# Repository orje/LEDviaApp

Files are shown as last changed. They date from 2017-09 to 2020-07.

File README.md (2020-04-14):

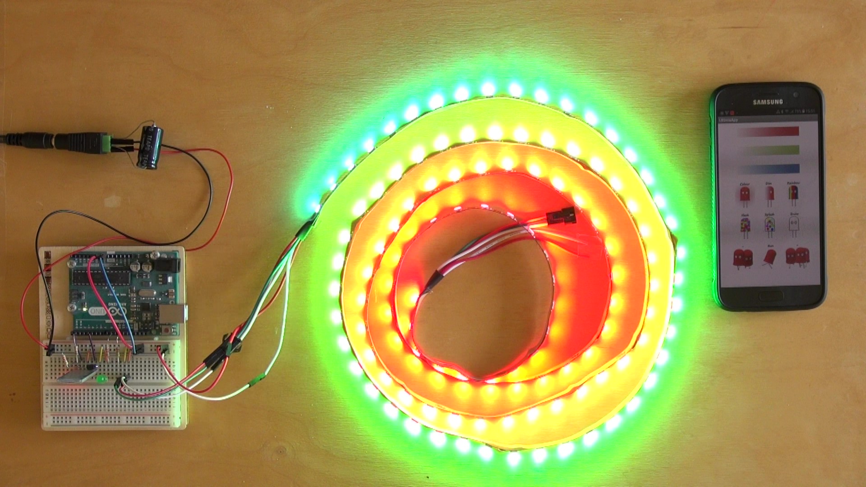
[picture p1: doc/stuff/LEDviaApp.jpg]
Demo video
  
[Demo video](https://youtu.be/p4o3Cnaa4Ys)

#### See the Wiki for further informations!
###### This file is at least needed. The ino file is generated throughout QM.
* LEDviaApp.qm = QM model file  
###### These files are originally [from](https://github.com/nickgammon/NeoPixels_SPI) here.
* NeoPixels_SPI.cpp = library from Nick Gammon  
* NeoPixels_SPI.h = library from Nick Gammon  
###### The app file:
* aia = exported source file for import in MIT App Inventor 2

###### The doc directory includes further files and informations.

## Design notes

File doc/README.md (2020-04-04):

* MIT App Inventor 2 apk file for installation  
* Fritzing file  
* pictures of breadboard and circuit

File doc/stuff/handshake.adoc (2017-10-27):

[uml,handshake.png]
----

hide footbox

title handshake between handy and Arduino

actor user #orange
control app #steelblue
entity handy #steelblue
entity Arduino #green
control sketch #green
entity LED #red

autonumber "<b>  #"

activate LED

Arduino -[#green]> sketch: Q_TIMEOUT

sketch <-[#green] Arduino: no request

sketch -[#green]> LED: control LED

user -[#orange]> app: input

== app starts handshake ==

app -[#steelblue]> Arduino: no communication ongoing \n send request 'R'

note right #lightgrey
byte goes straight
into receive buffer
end note

Arduino -[#green]> sketch: Q_TIMEOUT

sketch <-[#green] Arduino: see request 'R'

deactivate LED

== sketch continues handshake==

sketch -[#green]> handy: send transmit 'T'

handy -[#steelblue]> app: Clock Timer

app <-[#steelblue] handy: see permission 'T'

app -[#steelblue]> Arduino: send message '<XY>'

Arduino -[#green]> sketch: Q_TIMEOUT

sketch <-[#green] Arduino: get message '<XY>'

sketch -[#green]> handy: on stop sign '>' \n send acknowledge 'A'

== sketch ends handshake ==

sketch -[#green]> LED: control LED

activate LED

handy -[#steelblue]> app: Clock Timer

app <-[#steelblue] handy: see acknowledge 'A' \n end communication

== app ends handshake ==

Arduino -[#green]> sketch: Q_TIMEOUT

sketch <-[#green] Arduino: no request

sketch -[#green]> LED: control LED

----

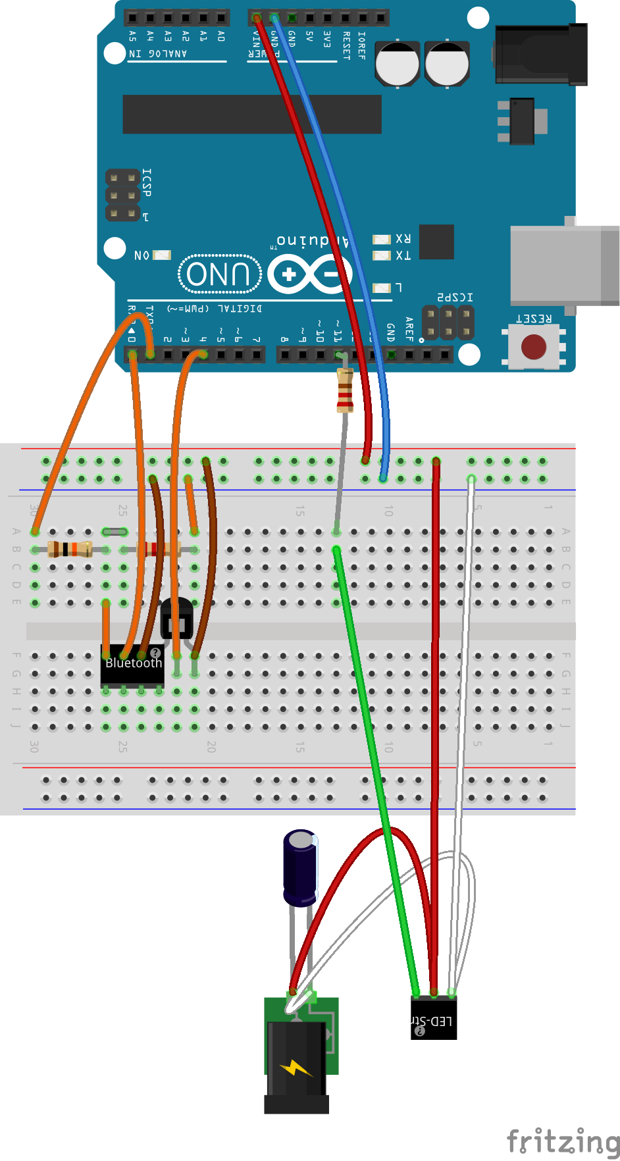
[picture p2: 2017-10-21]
doc/LEDviaApp_UNO_breadboard.png

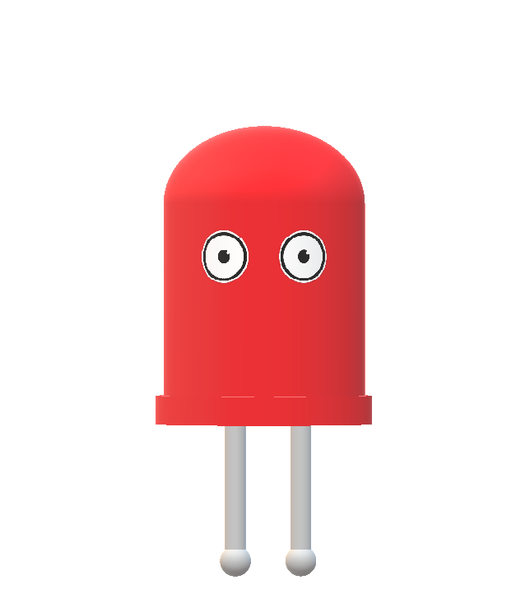
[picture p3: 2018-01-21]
doc/stuff/LedManV3/LedManWorkV3 - Kopie.png

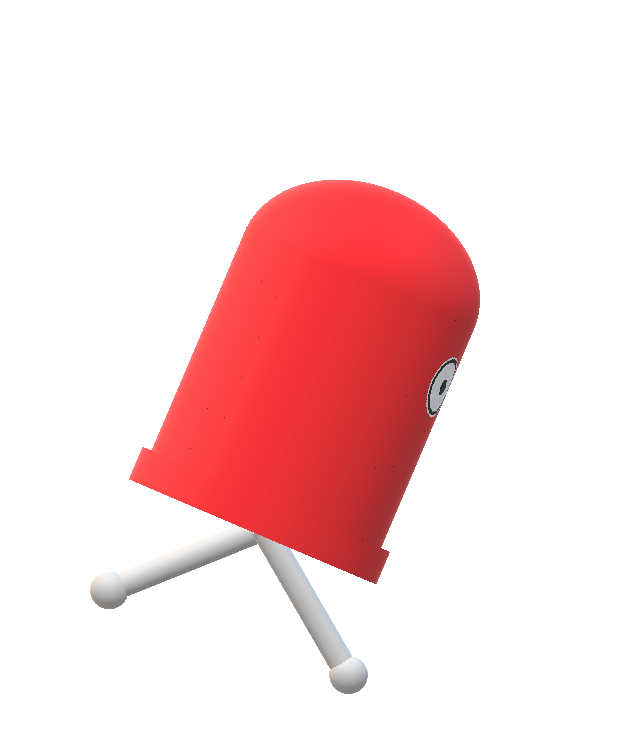
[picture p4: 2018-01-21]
doc/stuff/LedManV3/LedManRunV3.png

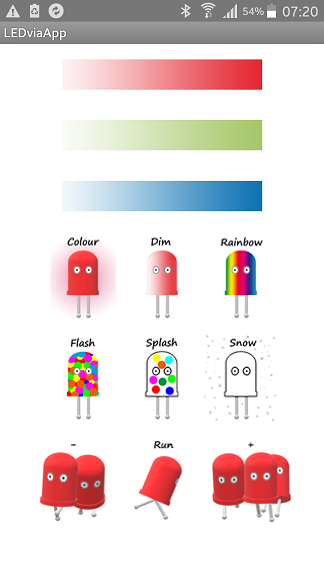
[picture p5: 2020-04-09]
doc/stuff/App.png

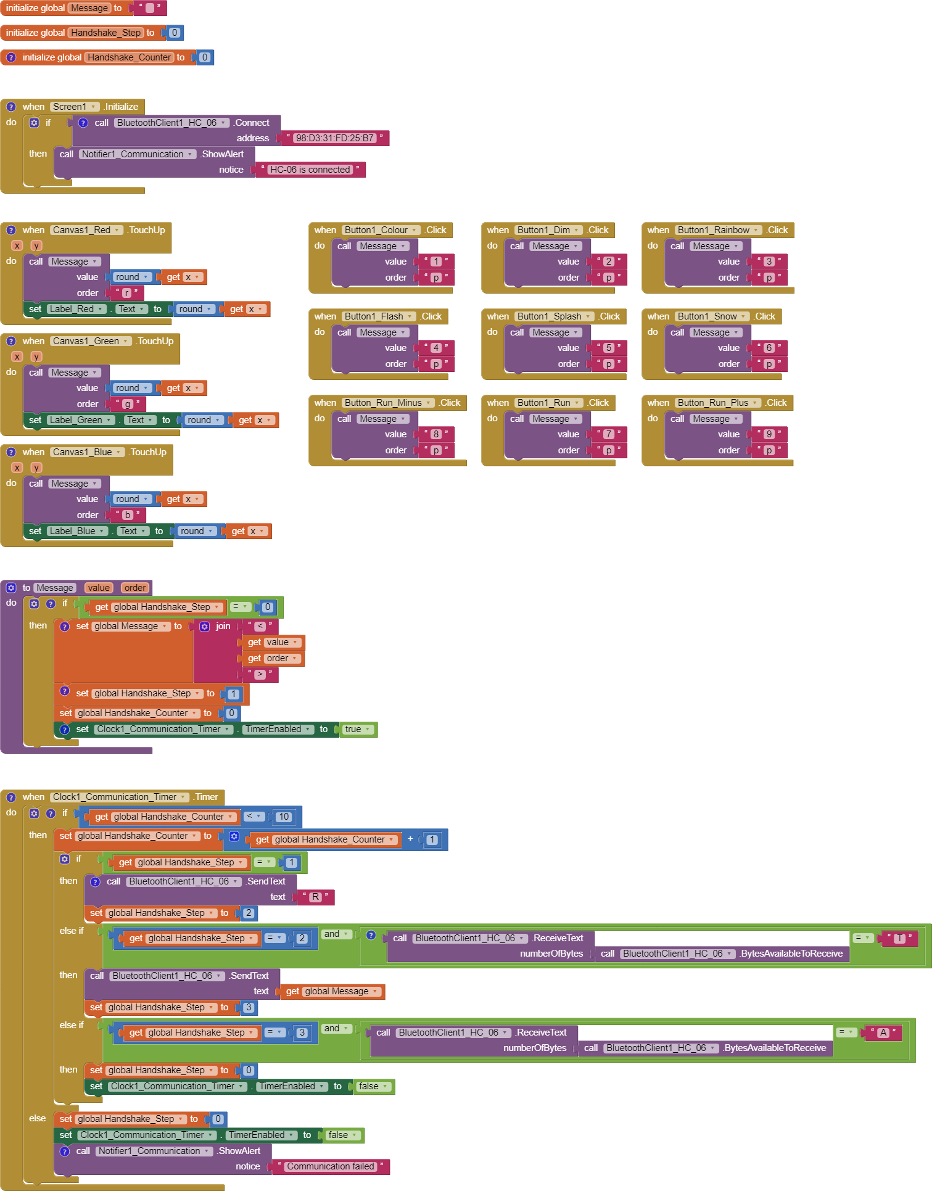
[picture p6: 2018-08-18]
doc/stuff/blocks.png

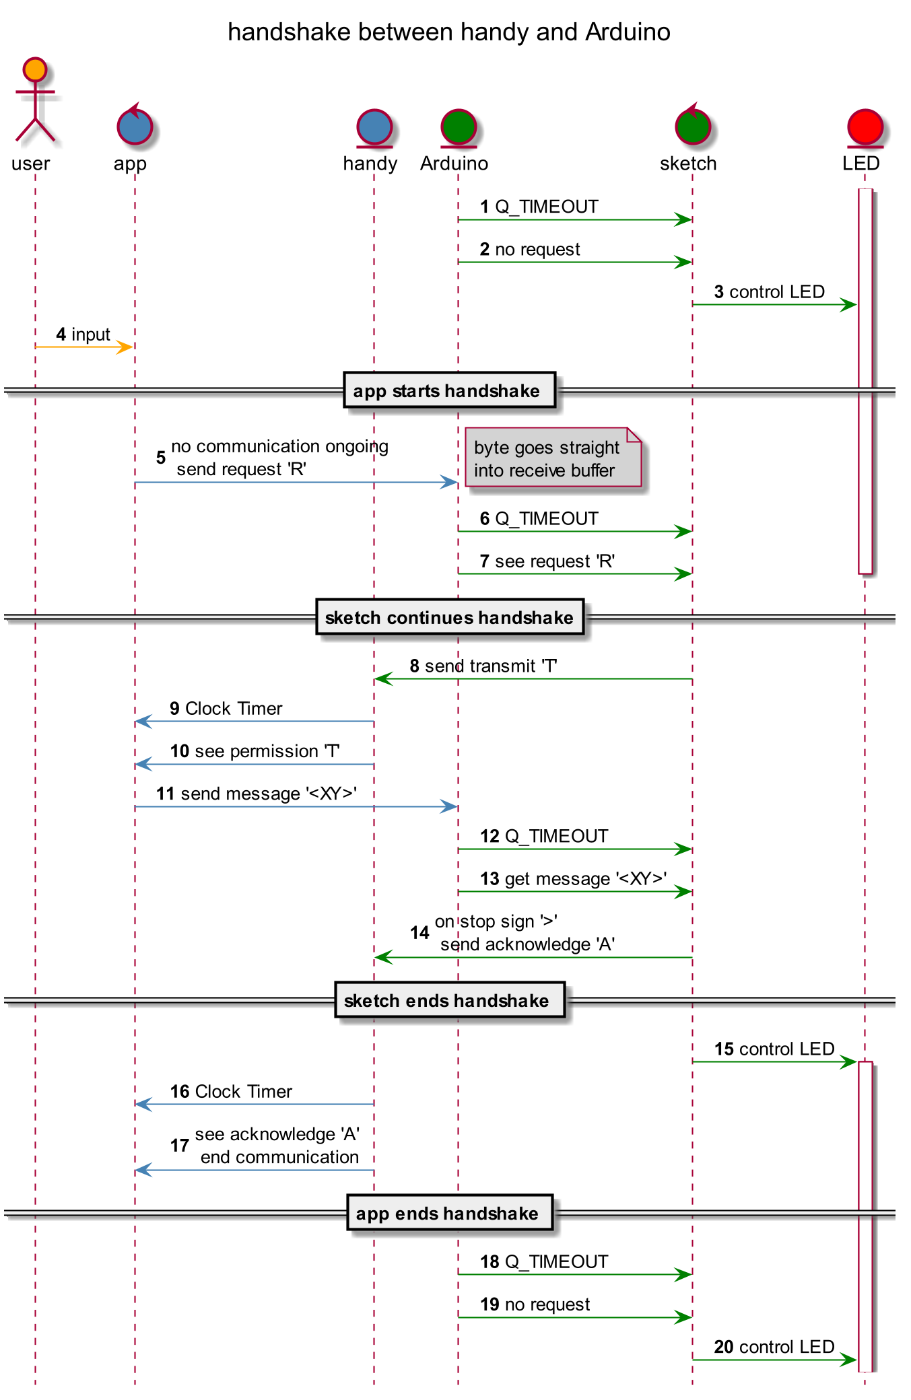
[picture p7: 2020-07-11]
doc/stuff/handshake.png

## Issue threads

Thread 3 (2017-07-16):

Initialisierungs-Datenübertragung bei Neuverbindung

orje, 2017-07-16:
Wenn bereits ein Anzeige-Programm im UNO läuft, muss ich bei einer Neuverbindung z.B. zu einem späteren Zeitpunkt erst einmal alle Werte auf 0 setzen und übertragen, sonst arbeiten app und sketch mit unterschiedlichen Werten und ich müsste erst einmal manuell alles auf 0 stellen.

orje, 2017-07-28:
Nicht wirklich nötig. Dann muss eben nach einer Neuverbindung die Werte so eingestellt werden, wie man sie haben möchte.

Closed 2017-07-28.

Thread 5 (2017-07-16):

Farbschieber auf 0 - 255 begrenzen

orje, 2017-07-16:
Z.Z. ist die Werteermittelung der Schieber irgendwie an die Bildschirmbreite gebunden. Daher ist es möglich, Werte > 255 einzustellen. Das stört zwar nicht, da sie schlichtweg nicht umgesetzt werden können, Ist aber ein Schönheitsfehler.

orje, 2017-07-28:
oder auch nicht

Closed 2017-07-28.

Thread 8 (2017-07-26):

Teststellung

orje, 2017-07-26:
Das Handy ballert die Werte einfach nur so raus. Das model reagiert auf den Interrupt der seriellen Schnittstelle und setzt die Befehle um, auch mitten in der Led Ansteuerung.

Die Interruptabschaltung in der libary und im model, während  LED-Ansteuerung, auskommentieren.

Was passiert aber dann, wenn zu jedem x-beliebigen Zeitpunkt eine Kommunikation reinkommt und die Led Ansteuerung unterbrochen und wieder neu/anders aufgenommen wird?

orje, 2017-07-28:
Habe alte Tests gefunden, welche darauf deuteten, dass es ohne Handshake nicht ordentlich funktioniert.

Closed 2017-07-28.

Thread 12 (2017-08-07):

Umgang mit Kommunikationshängern implementieren

orje, 2017-08-07:
Einen Zähler oder eine weitere Zykluszeitüberwachung mit der Kommunikation starten, um Hänger abzufangen.

orje, 2017-10-20:
bzw. asserts implentieren

orje, 2018-02-09:
Ebenso die Bluetooth Verbindung checken

orje, 2018-02-16:
done

Closed 2018-02-16.

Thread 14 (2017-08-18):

model restrukturieren

orje, 2017-08-18:
Um es noch übersichtlicher zu gestalten, könnte ich analog zum state communication im state branch von Q_TIMEOUT aus 4 choices machen, statt alles in der entry action abzufragen.
Dann würden sogar die events (DISPLAY, RUNNING_LIGHT, DIMMING) wegfallen.

orje, 2017-10-19:
Geht nicht so einfach, da zwei choices hintereinander geschaltet werden müssten (z.B. dimmen und dann up oder down)

Closed 2017-10-19.

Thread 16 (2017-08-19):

transition to history integrieren

orje, 2017-08-19:
Für die Rückkehr von state communication zu state branch nutzbar, um zum letzten aktiven program oder zu state display als default zu springen?

orje, 2017-09-03:
bringt nichts

Closed 2017-09-03.

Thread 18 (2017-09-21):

ursprüngliche Schieber testen

orje, 2017-09-21:
Theoretisch dürfte es nun keine Hänger mehr geben, da auf Seiten der App die Kommunikation und auf Seiten des UNO 1 LED-Zyklus erst abgeschlossen sein muss, bevor die nächste folgen kann.

orje, 2017-09-21:
gelabelt

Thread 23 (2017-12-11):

Anzahl der LED beim Lauflicht wählbar gestalten

orje, 2017-12-11:
Variante 1: Zahleneingabe
Variante 2: + oder - mit Zähler

orje, 2017-12-11:
Funktionsausbau

orje, 2018-01-02:
Zu 99% erledig.
Zwei Punkte sind mir unklar:
- Das Erreichen der Endpunkte (PIXELS und 0) ist unterschiedlich.
- Die Anzahl kann nicht bis auf Maximum (PIXELS und 0) geschraubt werden.

Closed 2018-01-02.

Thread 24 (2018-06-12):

aktuellen Farbwert in der App anzeigen

orje, 2018-06-12:
Die Programme Colour, Dim und Run arbeiten mit den Farben der Schieberegler. Die aktuell eingestellte Farbe sollte angezeigt werden.
Die Programme Rainbow, Flash, Splash und Snow generieren ihre eigenen Farbwerte.

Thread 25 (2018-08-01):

snow ist blöd

orje, 2018-08-01:
Der Schnee soll von oben nach unten fallen und ggf. sich über einen gewissen Zeitrum von unten nach oben stapeln.

orje, 2018-08-15:
oder schmilzen

orje, 2018-08-27:
Denkfehler, da ich nur mit dem 8 LED Pixel stick stehend teste. Der LED stripe wird horizontal angebracht und damit gibt's kein "von oben, nach unten".

Closed 2018-08-27.

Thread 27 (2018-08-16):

Handling des Kommunikationsfehlers vom Arduino bearbeiten

orje, 2018-08-16:
neuer Kommunikationsversuch der App setzt Fehler Led zurück

orje, 2018-08-27:
Ist ein Problem des neuen builds des MIT App Inventor 2.
Der legacy build funkitoniert.

Closed 2018-08-27.

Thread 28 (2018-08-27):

automatic reset of the Arduino, if communication hangs

orje, 2018-08-27:

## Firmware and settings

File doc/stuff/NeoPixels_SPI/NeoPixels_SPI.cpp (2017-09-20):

/*
 *
 * NeoPixel display library.
 *
 * Author: Nick Gammon
 * Date:   2nd March 2016
 *
 * With ideas from: http://wp.josh.com/2014/05/13/ws2812-neopixels-are-not-so-finicky-once-you-get-to-know-them/
 *
 * Designed for 16 MHz processor.
 *
 * Released for public use under the Creative Commons Attribution 3.0 Australia License
 *      http://creativecommons.org/licenses/by/3.0/au/
 *
 * In other words, if you use this code, please give me the credit for writing the library.
 *
 * Time taken to display: About 63 µs per pixel (21 µs per byte, about 2.6 µs per bit).
 * This is 63 ms to display 1000 pixels, roughly 16 refreshes per second (16 FPS)
 *   Of course, with less pixels the frame rate will go up.
 *
  HOW TO USE
    ledsetup ();         - Get ready to send.
                           Call once at the beginning of the program.
    sendPixel (r, g, b); - Send a single pixel to the string.
                           Call this once for each pixel in a frame.
                           Each colour is in the range 0 to 255.
    show ();             - Latch the recently sent pixels onto the LEDs .
                           Call once per frame.
    showColor (count, r, g, b); - Set the entire string of count Neopixels to this one colour.
                                  This automatically turns interrupts off, so you don't need to do it.
    Note that if you are sending individual pixels (with sendPixel) you should first call
    noInterrupts(), send all the pixels you need, and then call interrupts(). Otherwise a timer or
    other interrupt may pause the sending long enough for the string to reset.
    For example:
    noInterrupts ();          // prevent interrupts while we are sending colours
    for (byte i = 0; i < 10; i++)
      {
      sendPixel (100, 0, 0);    // red
      sendPixel (0, 100, 0);    // green
      sendPixel (0, 0, 100);    // blue
      } // end of for loop
    interrupts ();            // interrupts are OK now
    show ();                  // latch the colours
 */

#include <SPI.h>
#include <NeoPixels_SPI.h>

// Note: Connect NeoPixels to MOSI (pin D11 on a Uno, pin D51 on a Mega)

void sendByte (byte b)
  {
    // send one byte to the Neopixels - note that the "off" gap is partly handled by the loop overhead
    // gaps measured empirically to be 1.7 µs to 2 µs, so we don't need to add any more of our own
    for (byte bit = 0; bit < 8; bit++)
      {
	// byte b mit 0x80 = binär 10000000 ausmaskieren. Ergebnis ist 1, wenn erstes bit von b auch 1 ist.
      if (b & 0x80) // is high-order bit set?
        SPI.transfer (0b11111100);  // 1 bit - 750 ns on + 250 ns off (acceptable "on" range 550 ns to 850 ns)
      else
        SPI.transfer (0b11100000);  // 0 bit - 375 ns on + 625 ns off (acceptable "on" range 200 ns to 500 ns)
	// b = b << 1
      b <<= 1; // shift next bit into high-order position
    } // end of for each bit
} // end of sendByte

void ledsetup()
{
  SPI.begin ();
  SPI.setClockDivider (SPI_CLOCK_DIV2);
  SPI.setBitOrder (MSBFIRST);
  SPI.setDataMode (SPI_MODE1);   // MOSI normally low.
  show ();                       // in case MOSI went high, latch in whatever-we-sent
  sendPixel (0, 0, 0);           // now change back to black
  show ();                       // and latch that
}  // end of ledsetup

void sendPixel (const byte r, const byte g, const byte b)
  {
  sendByte (g);        // NeoPixel wants colors in green-then-red-then-blue order
  sendByte (r);
  sendByte (b);
  } // end of sendPixel

// Just wait long enough without sending any bits to cause the pixels to latch and display the last sent frame
void show()
  {
  delayMicroseconds (9);
  } // end of show

// Display a single color on the whole string
void showColor (const unsigned int count, const byte r , const byte g , const byte b)
  {
  noInterrupts ();
  for (unsigned int pixel = 0; pixel < count; pixel++)
    sendPixel (r, g, b);
  interrupts ();
  show ();  // latch the colours
  } // end of showColor

// for the rainbow animation  
// Input a value 0 to 255 to get a color value.
// The colours are a transition r - g - b - back to r.
void Wheel (byte WheelPos, byte & r, byte & g, byte & b) {
  if (WheelPos < 85) {
    r = WheelPos * 3;
    g = 255 - WheelPos * 3;
    b = 0;
    }
  else if (WheelPos < 170) {
    WheelPos -= 85;
    r = 255 - WheelPos * 3;
    g = 0;
    b = WheelPos * 3;
    }
  else {
    WheelPos -= 170;
    r = 0;
    g = WheelPos * 3;
    b = 255 - WheelPos * 3;
    }
} // end of Wheel

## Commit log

2017-07-14 Erster Upload
    Upload der Code-Dateien und der Dokumentationen
    [LEDviaApp.fzz]
2017-07-16 Redaktionelle Änderungen und Ergänzungen
2017-07-18 Stripe mit 120 LED
2017-07-21 Versuch ein Bild in die README-Datei zu bekommen
2017-07-22 Bild der state machine anzeigen
2017-07-23 kleinere Korrekturen
    [LEDviaApp.fzz]
2017-07-23 redaktionelle Korrektur und inhaltliche Ergänzung
2017-07-26 model simplifiyng
    Auf Miro Samek's Anregung hin, habe ich das model vereinfacht, indem die Anzeige-Programme zu substates der Verzweigung wurden und dadurch nur noch ein Q_TIMEOUT benötigt wird.
    Dadurch wird allerdings die Möglichkeit für verschiedene Anzeige-Timings eingeschränkt.
2017-07-26 Bilder der State Machine aktualisiert
2017-07-27 expand the filter
2017-08-03 clarification
    What 'Time tick' is for the QP framework, is 'Clock Timer' for the App Inventor
2017-08-04 Test everything with LED stick
2017-10-19 use board led for debugging
2017-10-19 cleaning circuit
    [LEDviaApp.fzz]
2017-10-19 Micro breadboard
    [LEDviaApp_Micro.fzz]
2017-10-20 reorganizing resporitory
    [LEDviaApp_Micro.fzz, LEDviaApp_UNO.fzz]
2017-10-21 circuit without extern debug led
2017-10-21 adding suddirectory for Arduino Micro
    [LEDviaApp_Micro.fzz]
2017-10-22 adding SPI link
2017-10-24 clean up
    [LEDviaApp_Micro.fzz]
2017-12-25 tests for more running led
2017-12-31 using NG's array
    have to calculate into an array, before sending to the LED stripe because of timing problems
2018-01-02 finished more Running LED
2018-02-16 adjust the sketch communication counter
    The Arduino probably won't have a problem in the communication
2018-02-16 adjust the communication timer of the app and the counter
2018-08-11 communication check, qm version
    The counter of the communication check in the qm model and the app were raised to 20 tries. They were probably to strict.
    The versions of QP, QM and Arduino ide were raised.
2018-10-11 Update .LEDviaApp
    unimportant
2020-04-01 modifications after qm update
    Since QM now uses the Arduino IDE to compile and upload
    - Arduino.h isn't used
    - Nick Gammon's library had to be moved to the Arduino library directory
    - the SPI library is now found at its originally path
2020-04-09 adjustments
    communication timer adjusted
